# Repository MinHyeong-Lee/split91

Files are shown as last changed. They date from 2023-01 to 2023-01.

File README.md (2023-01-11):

# split91 keyboard - Split Keyboard with right-hand B


This keyboard is based on [split89](https://github.com/jurassic73/split89)

I wanted a keyboard that is familiar with 87% array usage, requires a direction key, and has a Function key.
Most split keyboards have a unique arrangement that requires time to adapt.

By chance, I found [split89](https://github.com/jurassic73/split89) on github, and I added B key to right-hand by modifying the stl files.
Thanks to [Jurassic73](https://github.com/jurassic73) for sharing a good keyboard and I would like to share my revised stl files and hex file here.

**External Links**  
[QMK Official Documentation](https://docs.qmk.fm/#/) - You can solve any problems that arise during compile of qmk firmware.  
[Vial](https://get.vial.today/) - open-source cross-platform (Windows, Linux and Mac) GUI and a QMK fork for configuring your keyboard in real time.

**Modifications**
1. Add B key to right-hand
2. Add Rotary-encoder under right B key (This is just an option. You can use a mechanical keyboard switch, not rotary encoder)
3. Compiled Vial firmware for split91 keyboard

**Table of Contents**  
[Bill of Materials](#bill-of-materials)  
[Assembly](#assembly)  

# Bill of Materials  
  * 3d printed components in [3d_printing_stl_files](https://github.com/MinHyeong-Lee/split91/tree/main/3d_printing_stl_files) directory  
  * [tolerance_with_1mm](https://github.com/MinHyeong-Lee/split91/tree/main/3d_printing_stl_files/tolerance_with_1mm) - 1mm tolerance stl files 
  * [tolerance_with_2mm](https://github.com/MinHyeong-Lee/split91/tree/main/3d_printing_stl_files/tolerance_with_2mm) - 2mm tolerance stl files  
  * [TEST.stl](https://github.com/MinHyeong-Lee/split91/blob/main/3d_printing_stl_files/TEST.stl) - Check the tolerance of the 3d printer you have in the TEST.stl file output.  test image

    **Print one of each:**  
      split91_electronics_plate_left.stl  
      split91_electronics_plate_right.stl  
      split91_left_body.stl  
      split91_left_body_base.stl  
      split91_left_wrist_base.stl  
      split91_left_wrist_pad.stl  
      split91_right_body.stl  
      split91_right_body_base.stl  
      split91_right_wrist_base.stl  
      split91_right_wrist_pad.stl  
    **Print two of each:**  
      split91_arduino_brace.stl  
      split91_reset_button_brace.stl  
      split91_trrs_jack_brace.stl  

If you assemble all of parts after print out stl files, it is as follows.  
split91_full_shot

  * [components.png](https://github.com/MinHyeong-Lee/split91/blob/main/3d_printing_stl_files/components.png) - Materials required for assembly
  * (2) Pro Micro ATmega32U4 (5v 16MHz USB micro)  
  
  * (1) 3.5mm TRS or TRRS male to male cable - Transfer power from Master to Slave  
  * (1) 2k-10k resistor  
  * (2) Tactile Micro vertical mount switch (6mmx6mmx8mm total height / 4.5mm button height) - [Aliexpress](https://aliexpress.com/item/1005002723897755.html?spm=a2g0o.order_list.order_list_main.35.383d140fhr34a7)    
  * (90) Mechanical Keyboard Switches  
  * (90) Key caps  
  * (1) EC11 Rotary Encoder (If you don't need encoder, then need one more switch and keycap)
  * (6) 2U plate mount key switch stabilizers  
  * (2) space bar keys - 2.25u / 2.75u  
  * Wire - 6 color helps you keep track of what's where.  
  * (91) 1N4148 Diodes  
  * (19) 10mm M3 Screw  
  * (20) 3x5t Neodymium round magnet  
  * (22) 5x3t Neodymium round magnet  
  * (4) 10x3t Neodymium round magnet  
  * (4) 10x5t Neodymium round magnet  
  * 3M Rubber feet - [Amazon](https://www.amazon.com/gp/product/B00K6RZ9Q2/)  

# Assembly  
It is recommended to refer to [split89](https://github.com/jurassic73/split89) for the overall build guide. It is written in great detail.  
I will only fill out the changed parts according to the addition of the switch.  

## left body
left body  
left body is as same as split89  

## right body
wire  
Row and column connection of the right body is shown in the picture above.  
This is a wirring that matches the keymap I uploaded. If you plan to compile qmk firmware yourself, you can change wirring.  
Ignore the blue line and look at the red line.  

## Attaching Left, Right Base and Left, Right Body
split89 used an M3 screw for assembling the top and bottom plates.  
However, split91 uses a magnet to attach the top and bottom plates.  
The left body is small in size, so the top and bottom plates are well attached.  
On the other hand, the output of right body has shrinkage. I think it's because the thickness is thin and the length is long.  
It is a disadvantage that may occur while using a magnet, so you may need to use a screw or an adhesive if you want.  

### Rotary Encoder
Two additional pins are required to soldering rotary encoder.
Here's the way. [Making two more pins available](https://golem.hu/guide/pro-micro-upgrade/)  
  
  
  

## Keyboard Layout
keyboard-layout (1)  
Keyboard layout with Encoder for Vial  

## Controller Programming
Using [QMK Toolbox](https://github.com/qmk/qmk_toolbox/releases) for flashing [hex file](https://github.com/MinHyeong-Lee/split91/blob/main/split91_vial.hex)  
Both left body and right body should be flashed.  
You can connect usb anywhere on the left or right when you actually use it.  

After flashing, you can use Vial for your keyboard  
  

firmware size

Vial is convenient but has a large firmware size.
I tried to reduce the size of the firmware, but I can use only 3 layers.  
You will be able to increase the number of the layer by compiling yourself except for features that you do not use among Mouse Key and Tab dance, Combo, and Media.  

If you want to compile firmware, clone [vial-qmk](https://github.com/vial-kb/vial-qmk) and move this repo into vial-qmk/keyboards/  

    cd ~/
    git clone https://github.com/MinHyeong-Lee/split91.git
    git clone https://github.com/vial-kb/vial-qmk.git
    mv -r split91 ~/vial-qmk/keyboards/
    cd vial-qmk
    qmk compile -j 8 -kb split91 -km vial

## License  
✖ | Commercial Use

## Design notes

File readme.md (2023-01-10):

# minhyeong91

minhyeong91

*A short description of the keyboard/project*

* Keyboard Maintainer: [MinHyeong-Lee](https://github.com/MinHyeong-Lee)
* Hardware Supported: *The PCBs, controllers supported*
* Hardware Availability: *Links to where you can find this hardware*

Make example for this keyboard (after setting up your build environment):

    make minhyeong91:default

Flashing example for this keyboard:

    make minhyeong91:default:flash

See the [build environment setup](https://docs.qmk.fm/#/getting_started_build_tools) and the [make instructions](https://docs.qmk.fm/#/getting_started_make_guide) for more information. Brand new to QMK? Start with our [Complete Newbs Guide](https://docs.qmk.fm/#/newbs).

## Bootloader

Enter the bootloader in 3 ways:

* **Bootmagic reset**: Hold down the key at (0,0) in the matrix (usually the top left key or Escape) and plug in the keyboard
* **Physical reset button**: Briefly press the button on the back of the PCB - some may have pads you must short instead
* **Keycode in layout**: Press the key mapped to `QK_BOOT` if it is available

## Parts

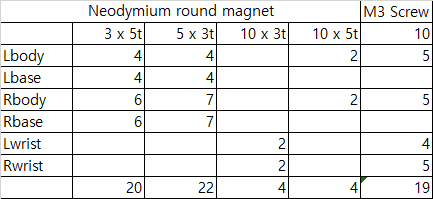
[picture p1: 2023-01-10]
3d_printing_stl_files/components.png

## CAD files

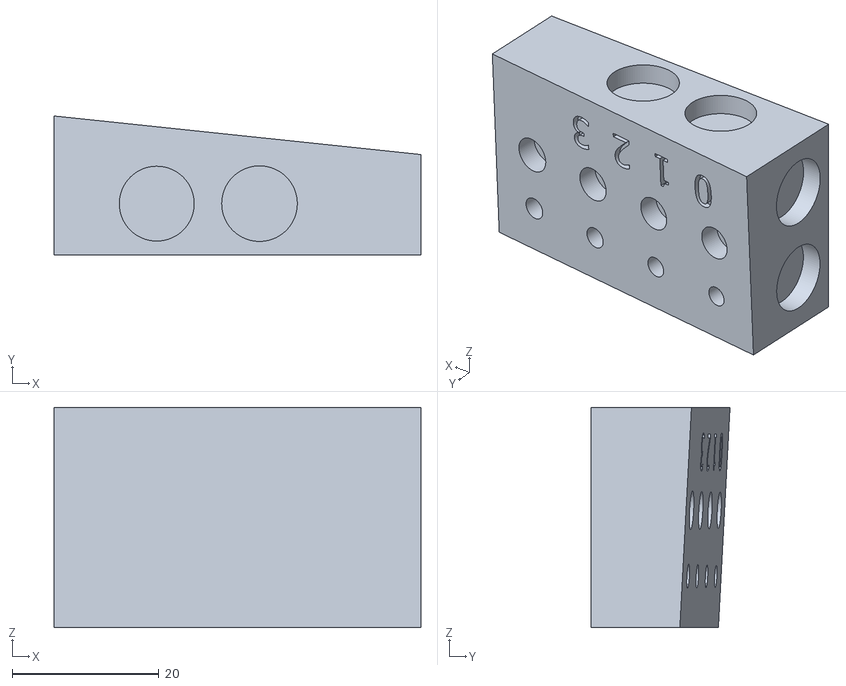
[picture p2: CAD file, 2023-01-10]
3d_printing_stl_files/TEST.stl
50.0 x 18.9 x 30.0

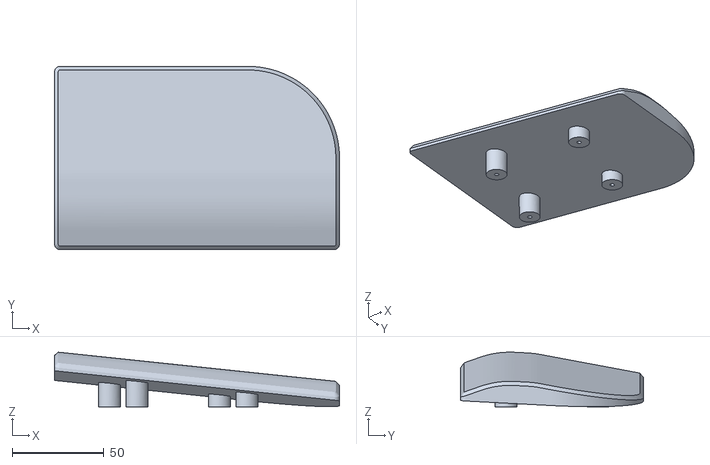
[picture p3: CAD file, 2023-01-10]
3d_printing_stl_files/tolerance_with_1mm/split91_left_wristcover.stl
155.6 x 100.0 x 29.9

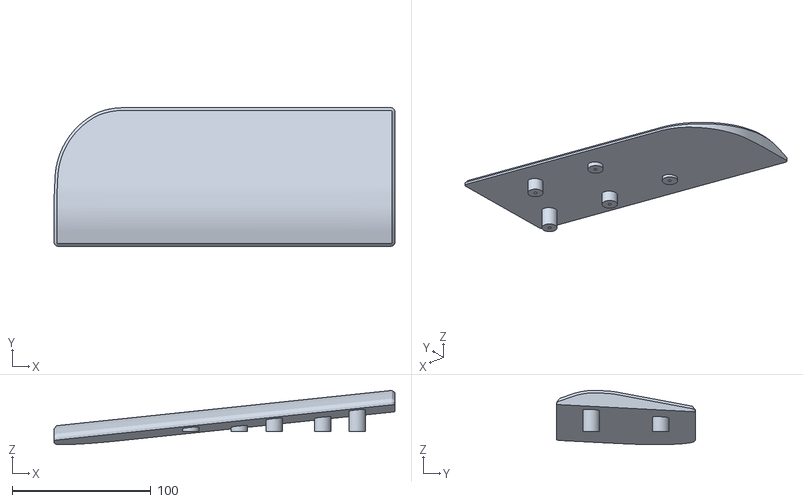
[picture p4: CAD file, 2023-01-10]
3d_printing_stl_files/tolerance_with_2mm/split91_right_wristcover.stl
246.0 x 100.0 x 39.2

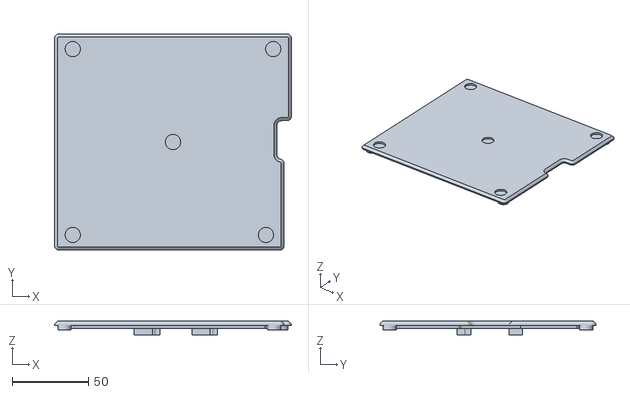
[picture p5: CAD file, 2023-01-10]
3d_printing_stl_files/tolerance_with_1mm/split91_left_base.stl
155.6 x 142.0 x 9.10

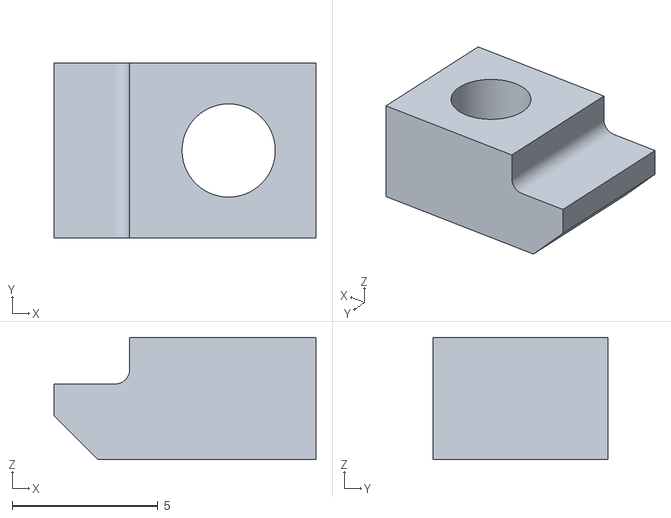
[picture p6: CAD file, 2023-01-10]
3d_printing_stl_files/tolerance_with_2mm/split91_trrs_jack_brace.stl
9.00 x 6.00 x 4.20

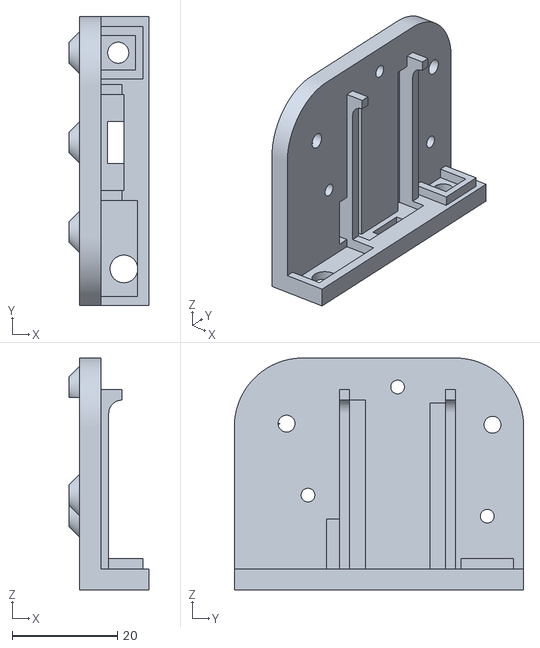
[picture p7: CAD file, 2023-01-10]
3d_printing_stl_files/tolerance_with_1mm/split91_electronics_plate_right.stl
15.1 x 54.9 x 44.0

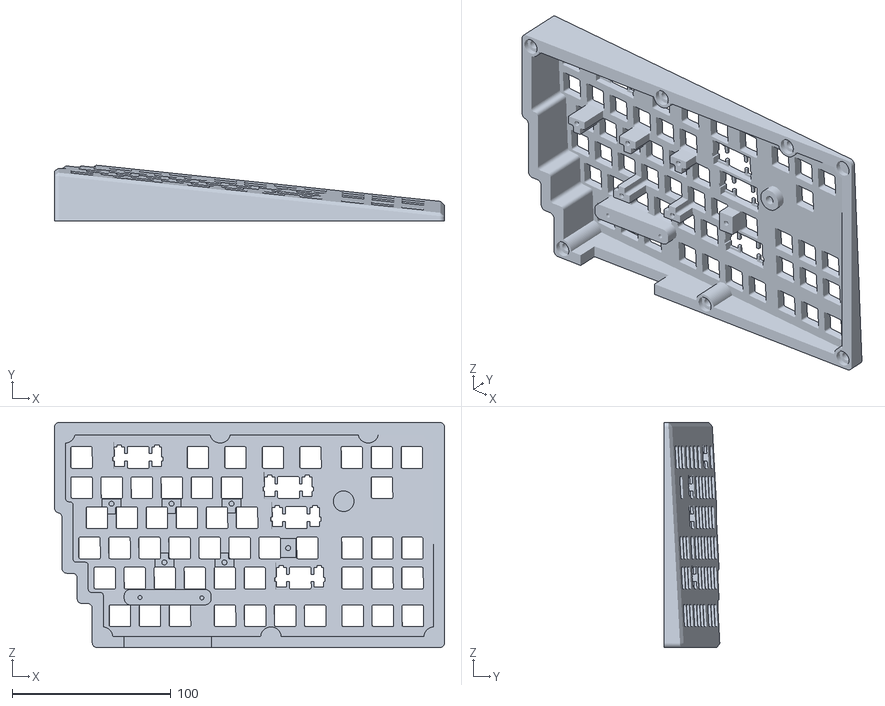
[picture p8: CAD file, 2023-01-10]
3d_printing_stl_files/tolerance_with_2mm/split91_right_body.stl
246.0 x 35.1 x 142.0

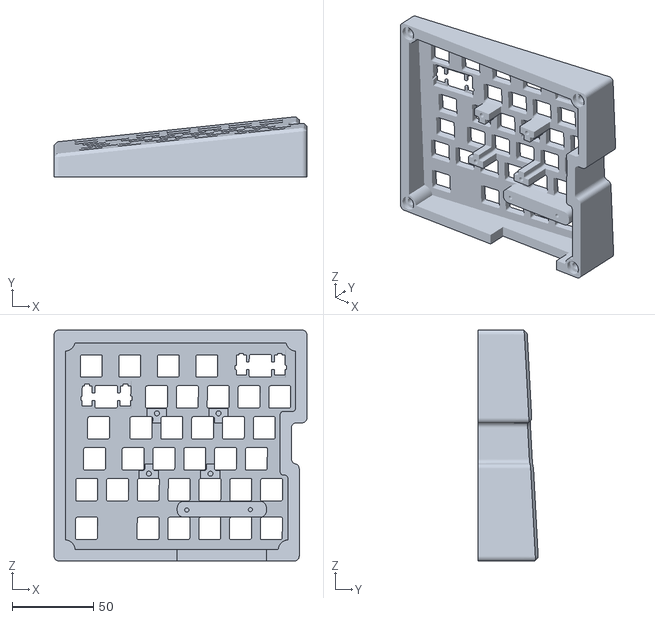
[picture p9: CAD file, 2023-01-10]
3d_printing_stl_files/tolerance_with_1mm/split91_left_body.stl
155.6 x 37.1 x 142.0

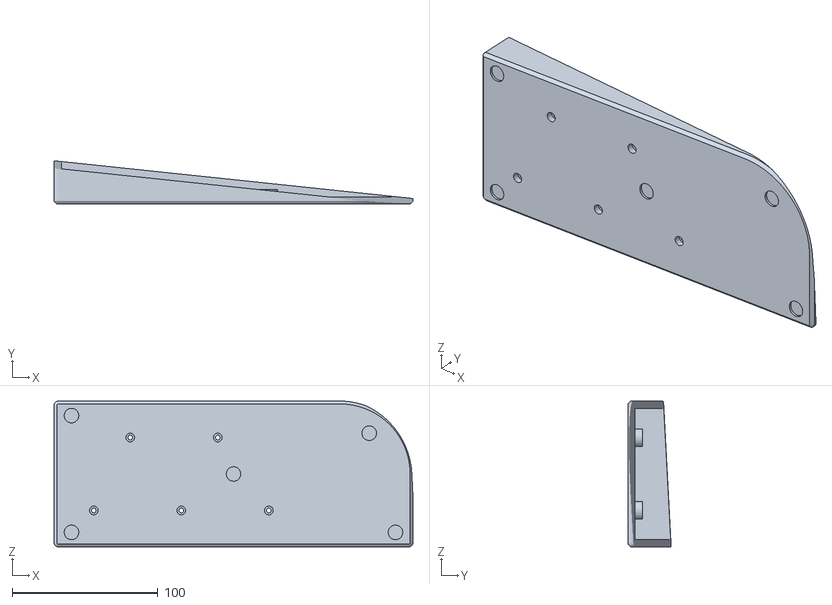
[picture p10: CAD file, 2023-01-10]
3d_printing_stl_files/tolerance_with_1mm/split91_right_wrist.stl
246.0 x 29.5 x 100.0

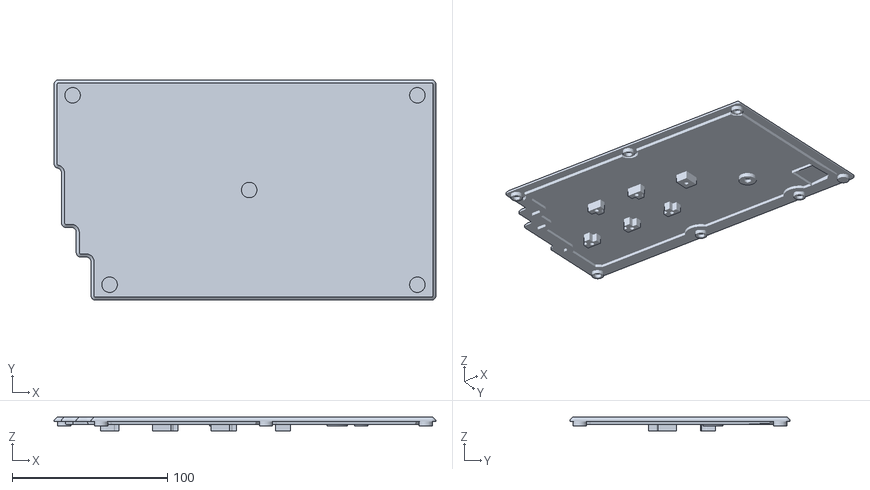
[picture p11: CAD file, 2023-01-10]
3d_printing_stl_files/tolerance_with_1mm/split91_right_base.stl
246.0 x 142.0 x 9.10

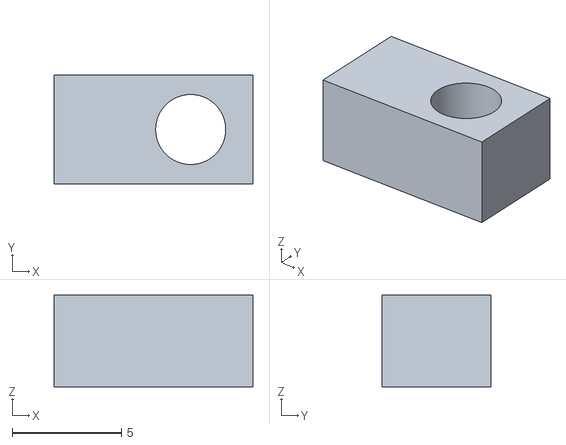
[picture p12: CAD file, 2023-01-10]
3d_printing_stl_files/tolerance_with_2mm/split91_reset_button_brace.stl
9.10 x 5.00 x 4.20

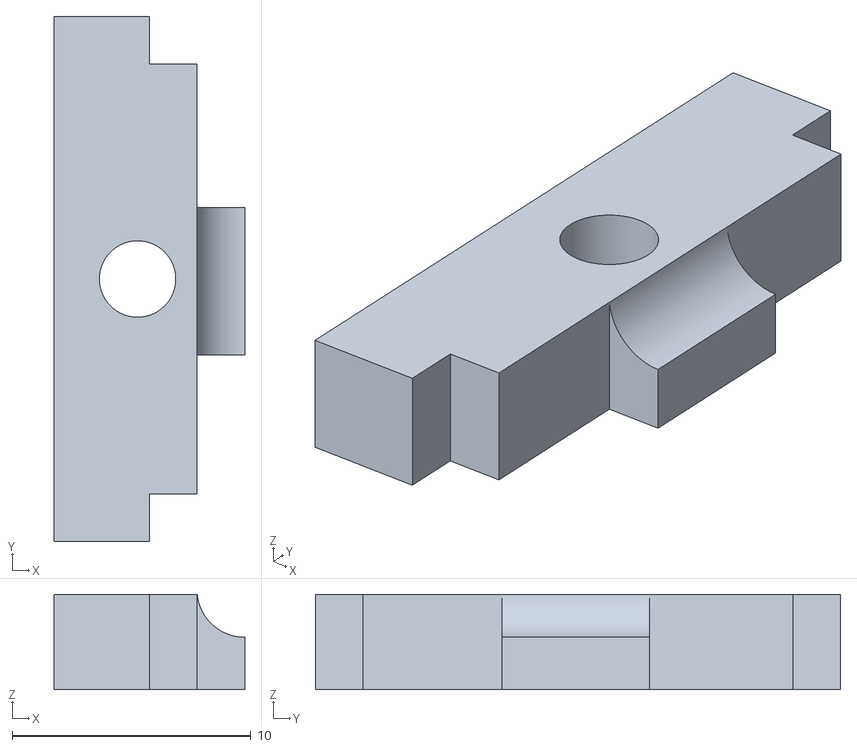
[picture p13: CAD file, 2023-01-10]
3d_printing_stl_files/tolerance_with_2mm/split91_arduino_brace.stl
8.00 x 22.0 x 4.00

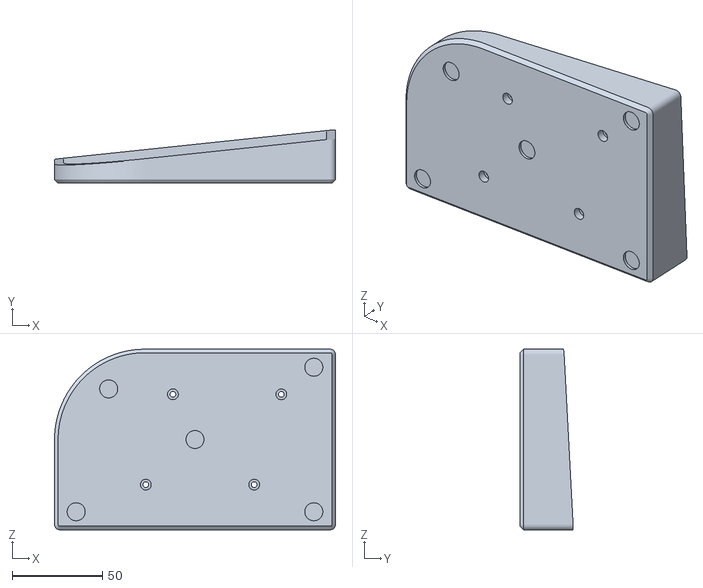
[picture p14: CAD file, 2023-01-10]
3d_printing_stl_files/tolerance_with_1mm/split91_left_wrist.stl
155.6 x 29.5 x 100.0

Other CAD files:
3d_printing_stl_files/tolerance_with_2mm/split91_right_wrist.stl
3d_printing_stl_files/tolerance_with_1mm/split91_right_body.stl
3d_printing_stl_files/tolerance_with_2mm/split91_left_base.stl
3d_printing_stl_files/tolerance_with_1mm/split91_electronics_plate_left.stl
3d_printing_stl_files/tolerance_with_2mm/split91_electronics_plate_left.stl
3d_printing_stl_files/tolerance_with_2mm/split91_left_body.stl
3d_printing_stl_files/tolerance_with_2mm/split91_left_wrist.stl
3d_printing_stl_files/tolerance_with_2mm/split91_right_base.stl

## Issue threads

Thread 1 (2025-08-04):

프린팅 비용과 시간은 얼마정도 걸리셨는지 여쭤봐도 될까요?

khris, 2025-08-04:
자동으로 견적내주는 사이트에 견적을 올려봤더니 거의 100만원 가까이 나와서;;; 저도 메이커 스페이스의 3D 프린터를 사용해보려고 합니다.

혹시 대략적인 프린팅 시간과 비용(아마 필라멘트 가격일것으로 생각하지만요)에 대해 혹시 알 수 있을까요?

MinHyeong-Lee, 2025-08-04:
안녕하세요?
저는 3년전쯤 성수의 메이커스페이스 큐브 라는곳을 이용했었는데요,
예약을 하면 1인당 1kg 이내의 도면을 출력할 수 있습니다.

1kg 이상 출력할 경우 필라멘트를 본인이 하나 사서 시설에 기증하면 계속해서 이용 가능하구요.

지금은 어떤 시스템으로 운영되고 있는지 몰라 확인해보시면 좋을 것 같습니다. 그리구 거주하시는곳 주변의 메이커스페이스를 확인해보시는것두요..

다만 메이커스페이스의 3D프린터를 사용하게 되면 문제가 프린터마다 세팅이 달라서 출력 결과물의 틀어짐이 발생한다거나.. 그런경우가 종종 있을 수 있습니다 공용 프린터의 한계라 어쩔수 없는것같아요

그래서 저는 잘 나올때까지 몇개 버려가면서 뽑았구요

한 번 방문할때마다 프린터 한대씩 이용할 수 있어가지고 저는 출력 가능한 범위로 최대한 꽉꽉 채워서 5번정도 방문했던 것 같아요

외주맡기면 솔직히 기성품 사는게 낫습니다.. ㅋㅋ

더 궁금하신 점 있으시면  아래로 톡 주세요 답변드리겠습니다~

Split91
https://open.kakao.com/o/suJxbNKh

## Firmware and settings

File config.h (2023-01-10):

/*
Copyright 2023 MinHyeong-Lee

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
You should have received a copy of the GNU General Public License
along with this program.  If not, see <http://www.gnu.org/licenses/>.
*/

#pragma once

#include "config_common.h"

/* USB Device descriptor parameter */
// #define MANUFACTURER minhyeong
// #define PRODUCT      minhyeong-board



/*
 * Keyboard Matrix Assignments
 *
 * Change this to how you wired your keyboard
 * COLS: AVR pins used for columns, left to right
 * ROWS: AVR pins used for rows, top to bottom
 * DIODE_DIRECTION: COL2ROW = COL = Anode (+), ROW = Cathode (-, marked on diode)
 *                  ROW2COL = ROW = Anode (+), COL = Cathode (-, marked on diode)
 *
 */

/* key matrix size
ROWS = total count of rows for both sides - this is broken out accordingly in split.h
COLS = number of cols per side which curently needs to be equal so there are blank columns for the left side in the split89.h file
 */
// #define MATRIX_ROWS 12
// #define MATRIX_COLS 10

/* Left side matrix */
#define MATRIX_ROW_PINS { F6, F7, B1, B3, B2, B6 }
#define MATRIX_COL_PINS { NO_PIN, NO_PIN, NO_PIN, NO_PIN, E6, D7, C6, D4, D2, D3}
/* Right side matrix */
#define MATRIX_ROW_PINS_RIGHT { F6, F7, B1, B3, B2, B6 }
#define MATRIX_COL_PINS_RIGHT { F5, F4, B5, B4, E6, D7, C6, D4, D2, D3 }

#define ENCODERS_PAD_A { B0 }
#define ENCODERS_PAD_B { D5 }
#define ENCODER_DIRECTION_FLIP

/* this will be tied to high (VCC with a 2k to 10k resistor) on the left keyboard half and tied to low (GND using a wire jumper only) on the right keyboard half.  This allows a user to plug in a USB cable to either side and function correctly with or without a TRS/TRRS cable with a single hex file. */
#define SPLIT_HAND_PIN D1

/* COL2ROW, ROW2COL */
#define DIODE_DIRECTION COL2ROW

/* handedness */
/*
 * Split Keyboard specific options, make sure you have 'SPLIT_KEYBOARD = yes' in your rules.mk, and define SOFT_SERIAL_PIN.
 */
#define USE_SERIAL
#define SOFT_SERIAL_PIN D0  // or D1, D2, D3, E6
#define SPLIT_USB_DETECT

//#define LED_NUM_LOCK_PIN B0
//#define LED_CAPS_LOCK_PIN B1
//#define LED_SCROLL_LOCK_PIN B2
//#define LED_COMPOSE_PIN B3
//#define LED_KANA_PIN B4

//#define BACKLIGHT_PIN B7
//#define BACKLIGHT_LEVELS 3
//#define BACKLIGHT_BREATHING

//#define RGB_DI_PIN E2
//#ifdef RGB_DI_PIN
//#    define RGBLED_NUM 16
//#    define RGBLIGHT_HUE_STEP 8
//#    define RGBLIGHT_SAT_STEP 8
//#    define RGBLIGHT_VAL_STEP 8
//#    define RGBLIGHT_LIMIT_VAL 255 /* The maximum brightness level */
//#    define RGBLIGHT_SLEEP  /* If defined, the RGB lighting will be switched off when the host goes to sleep */
/*== all animations enable ==*/
//#    define RGBLIGHT_ANIMATIONS
/*== or choose animations ==*/
//#    define RGBLIGHT_EFFECT_BREATHING
//#    define RGBLIGHT_EFFECT_RAINBOW_MOOD
//#    define RGBLIGHT_EFFECT_RAINBOW_SWIRL
//#    define RGBLIGHT_EFFECT_SNAKE
//#    define RGBLIGHT_EFFECT_KNIGHT
//#    define RGBLIGHT_EFFECT_CHRISTMAS
//#    define RGBLIGHT_EFFECT_STATIC_GRADIENT
//#    define RGBLIGHT_EFFECT_RGB_TEST
//#    define RGBLIGHT_EFFECT_ALTERNATING
/*== customize breathing effect ==*/
/*==== (DEFAULT) use fixed table instead of exp() and sin() ====*/
//#    define RGBLIGHT_BREATHE_TABLE_SIZE 256      // 256(default) or 128 or 64
/*==== use exp() and sin() ====*/
//#    define RGBLIGHT_EFFECT_BREATHE_CENTER 1.85  // 1 to 2.7
//#    define RGBLIGHT_EFFECT_BREATHE_MAX    255   // 0 to 255
//#endif

/* Debounce reduces chatter (unintended double-presses) - set 0 if debouncing is not needed */
#define DEBOUNCE 5

/* define if matrix has ghost (lacks anti-ghosting diodes) */
//#define MATRIX_HAS_GHOST

/* Mechanical locking support. Use KC_LCAP, KC_LNUM or KC_LSCR instead in keymap */
#define LOCKING_SUPPORT_ENABLE
/* Locking resynchronize hack */
#define LOCKING_RESYNC_ENABLE

/* If defined, GRAVE_ESC will always act as ESC when CTRL is held.
 * This is useful for the Windows task manager shortcut (ctrl+shift+esc).
 */
//#define GRAVE_ESC_CTRL_OVERRIDE

/*
 * Force NKRO
 *
 * Force NKRO (nKey Rollover) to be enabled by default, regardless of the saved
 * state in the bootmagic EEPROM settings. (Note that NKRO must be enabled in the
 * makefile for this to work.)
 *
 * If forced on, NKRO can be disabled via magic key (default = LShift+RShift+N)
 * until the next keyboard reset.
 *
 * NKRO may prevent your keystrokes from being detected in the BIOS, but it is
 * fully operational during normal computer usage.
 *
 * For a less heavy-handed approach, enable NKRO via magic key (LShift+RShift+N)
 * or via bootmagic (hold SPACE+N while plugging in the keyboard). Once set by
 * bootmagic, NKRO mode will always be enabled until it is toggled again during a
 * power-up.
 *
 */
//#define FORCE_NKRO

/*
 * Feature disable options
 *  These options are also useful to firmware size reduction.
 */

/* disable debug print */
//#define NO_DEBUG

/* disable print */
//#define NO_PRINT
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

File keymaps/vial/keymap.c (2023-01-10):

/* Copyright 2023 MinHyeong-Lee
 *
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
 * You should have received a copy of the GNU General Public License
 * along with this program.  If not, see <http://www.gnu.org/licenses/>.
 */
#include QMK_KEYBOARD_H

// #include "features/autocorrection.h"

bool process_record_user(uint16_t keycode, keyrecord_t* record) {
//   if (!process_autocorrection(keycode, record)) { return false; }
  // Your macros...

  return true;
}

#if defined(ENCODER_MAP_ENABLE)
const uint16_t PROGMEM encoder_map[][NUM_ENCODERS][2] = {
    [0] =  { ENCODER_CCW_CW(KC_MS_WH_UP, KC_MS_WH_DOWN) },
    [1] =  { ENCODER_CCW_CW(KC_MS_WH_UP, KC_MS_WH_DOWN) },
    [2] =  { ENCODER_CCW_CW(KC_MS_WH_UP, KC_MS_WH_DOWN) },
};
#endif

bool encoder_update_user(uint8_t index, bool clockwise) {
    if (index == 1) { /* First encoder */
        if (clockwise) {
            tap_code16(C(S(KC_TAB)));
        } else {
            tap_code16(C(KC_TAB));
        }
    }
    return true;
}

// Defines names for use in layer keycodes and the keymap
enum layer_names {
    BASE,
    AUD,
    TEMP,
};
const uint16_t PROGMEM keymaps[][MATRIX_ROWS][MATRIX_COLS] = {
    /* Base */
    [0] = LAYOUT(
        KC_ESC,     KC_F1,      KC_F2,      KC_F3,      KC_F4,      KC_F5,      KC_F6,      KC_F7,      KC_F8,      KC_F9,      KC_F10,     KC_F11,     KC_F12,     KC_PSCR,    KC_SCRL,    KC_PAUS,
        KC_1,       KC_2,       KC_3,       KC_4,       KC_5,       KC_6,       KC_7,       KC_8,       KC_9,       KC_0,       KC_MINS,    KC_EQL,     KC_BSPC,    KC_INS,     KC_HOME,    KC_PGUP,
        KC_GRV,     KC_Q,       KC_W,       KC_E,       KC_R,       KC_T,       KC_U,       KC_I,       KC_O,       KC_P,       KC_LBRC,    KC_RBRC,    KC_BSLS,    KC_DEL,     KC_END,     KC_PGDN,
        KC_TAB,     KC_A,       KC_S,       KC_D,       KC_F,       KC_G,       KC_Y,       KC_J,       KC_K,       KC_L,       KC_SCLN,    KC_QUOT,    KC_ENT,
        KC_CAPS,    KC_Z,       KC_X,       KC_C,       KC_V,       KC_B,       KC_H,       KC_0,      KC_M,       KC_COMM,    KC_DOT,     KC_SLSH,    KC_RSFT,                KC_UP,
        KC_LSFT,    KC_LCTL,    KC_LGUI,    KC_LALT,    MO(1),      KC_SPACE,   KC_B,       KC_N,       KC_SPACE,   KC_RALT,    KC_RGUI,    KC_APP,     KC_RCTL,    KC_LEFT,    KC_DOWN,    KC_RGHT
        ),
    /* Volume */
    [1] = LAYOUT(
        KC_TRNS,    KC_TRNS,    KC_TRNS,    KC_TRNS,    KC_TRNS,    KC_TRNS,                KC_TRNS,    KC_TRNS,    KC_TRNS,    KC_TRNS,    KC_TRNS,    KC_TRNS,    KC_TRNS,    KC_TRNS,    KC_TRNS,    KC_TRNS,
        KC_TRNS,    KC_TRNS,    KC_TRNS,    KC_TRNS,    KC_TRNS,    KC_TRNS,                KC_TRNS,    KC_TRNS,    KC_TRNS,    KC_TRNS,    KC_TRNS,    KC_TRNS,    KC_TRNS,    KC_TRNS,    KC_TRNS,    KC_TRNS,
        KC_TRNS,    KC_TRNS,    KC_TRNS,    KC_TRNS,    KC_TRNS,    KC_TRNS,                KC_TRNS,    KC_TRNS,    KC_TRNS,    KC_TRNS,    KC_TRNS,    KC_TRNS,    KC_TRNS,    KC_TRNS,    KC_TRNS,    KC_TRNS,
        KC_TRNS,    KC_TRNS,    KC_TRNS,    KC_TRNS,    KC_TRNS,    KC_TRNS,                KC_TRNS,    KC_TRNS,    KC_TRNS,    KC_TRNS,    KC_TRNS,    KC_TRNS,    KC_TRNS,
        KC_TRNS,    KC_TRNS,    KC_TRNS,    KC_TRNS,    KC_TRNS,    KC_TRNS,                KC_TRNS,    KC_TRNS,    KC_TRNS,    KC_TRNS,    KC_TRNS,    KC_TRNS,    KC_TRNS,                KC_VOLU,
        KC_TRNS,    KC_TRNS,    KC_TRNS,    KC_TRNS,    KC_TRNS,    KC_MEDIA_PLAY_PAUSE,    KC_TRNS,    KC_TRNS,    KC_TRNS,    KC_TRNS,    KC_TRNS,    KC_TRNS,    KC_TRNS,    KC_MPRV,    KC_VOLD,    KC_MNXT
        ),
    [2] = LAYOUT(
        KC_TRNS,    KC_TRNS,    KC_TRNS,    KC_TRNS,    KC_TRNS,    KC_TRNS,                KC_TRNS,    KC_TRNS,    KC_TRNS,    KC_TRNS,    KC_TRNS,    KC_TRNS,    KC_TRNS,    KC_TRNS,    KC_TRNS,    KC_TRNS,
        KC_TRNS,    KC_TRNS,    KC_TRNS,    KC_TRNS,    KC_TRNS,    KC_TRNS,                KC_TRNS,    KC_TRNS,    KC_TRNS,    KC_TRNS,    KC_TRNS,    KC_TRNS,    KC_TRNS,    KC_TRNS,    KC_TRNS,    KC_TRNS,
        KC_TRNS,    KC_TRNS,    KC_TRNS,    KC_TRNS,    KC_TRNS,    KC_TRNS,                KC_TRNS,    KC_TRNS,    KC_TRNS,    KC_TRNS,    KC_TRNS,    KC_TRNS,    KC_TRNS,    KC_TRNS,    KC_TRNS,    KC_TRNS,
        KC_TRNS,    KC_TRNS,    KC_TRNS,    KC_TRNS,    KC_TRNS,    KC_TRNS,                KC_TRNS,    KC_TRNS,    KC_TRNS,    KC_TRNS,    KC_TRNS,    KC_TRNS,    KC_TRNS,
        KC_TRNS,    KC_TRNS,    KC_TRNS,    KC_TRNS,    KC_TRNS,    KC_TRNS,                KC_TRNS,    KC_TRNS,    KC_TRNS,    KC_TRNS,    KC_TRNS,    KC_TRNS,    KC_TRNS,                KC_VOLU,
        KC_TRNS,    KC_TRNS,    KC_TRNS,    KC_TRNS,    KC_TRNS,    KC_MEDIA_PLAY_PAUSE,    KC_TRNS,    KC_TRNS,    KC_TRNS,    KC_TRNS,    KC_TRNS,    KC_TRNS,    KC_TRNS,    KC_MPRV,    KC_VOLD,    KC_MNXT
        ),
};

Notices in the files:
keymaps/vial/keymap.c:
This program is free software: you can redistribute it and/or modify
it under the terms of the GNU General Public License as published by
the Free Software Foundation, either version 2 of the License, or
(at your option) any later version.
